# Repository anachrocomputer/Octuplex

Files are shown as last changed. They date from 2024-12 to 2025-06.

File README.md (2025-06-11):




# Octuplex #

A 6502/6809 microcomputer in the shape of an octagon.

## Microprocessor ##

A choice of two classic 8-bit CPUs, the 6502 or the 6809.
The two chips have similar pinouts and are placed on the PCB overlapping.
Only one chip may be installed at a time.
Clock speed 2MHz in both cases,
with the 68B09 requiring a 4x clock input,
i.e. 8MHz.
The Hitachi 63B09 may also be fitted.

## Timer ##

The standard Motorola MC6840 timer chip.
Can generate interrupts and/or PWM signals.

## Parallel I/O ##

The standard 6522 parallel port chip.
Can generate interrupts.

Two handy little circuits for additional 8-bit I/O with minimal pin count: 74LS259 and 74LS251.
The 74LS259 is an unusual chip, an addressable latch.
It takes three address input pins and a single data input pin,
and has eight output pins.
The 74LS251 is an eight-input multiplexer with tri-state output.
The selector inputs are connected to three address pins,
while the output is connected to data bit D7.
The 6502's BIT instruction can read D7 directly into the sign flag,
which can be followed by BMI or BPL.

## Analog I/O ##

The classic Ferranti ZN428 8-bit DAC chip.

The classic Ferranti ZN448 b-bit ADC chip.
Although I'm not sure about this one due to its need for a negative supply rail.

## I2C Bus ##

Classic Philips PCF8584 I2C bus controller.
Can generate interrupts.

## Async Serial I/O ##

Rockwell R65C52 dual ACIA.
Can generate interrupts.

Motorola MC6850 with optocoupler for MIDI.
Can generate interrupts.

## Display ##

TBD, most likely an LED starburst display of some kind.

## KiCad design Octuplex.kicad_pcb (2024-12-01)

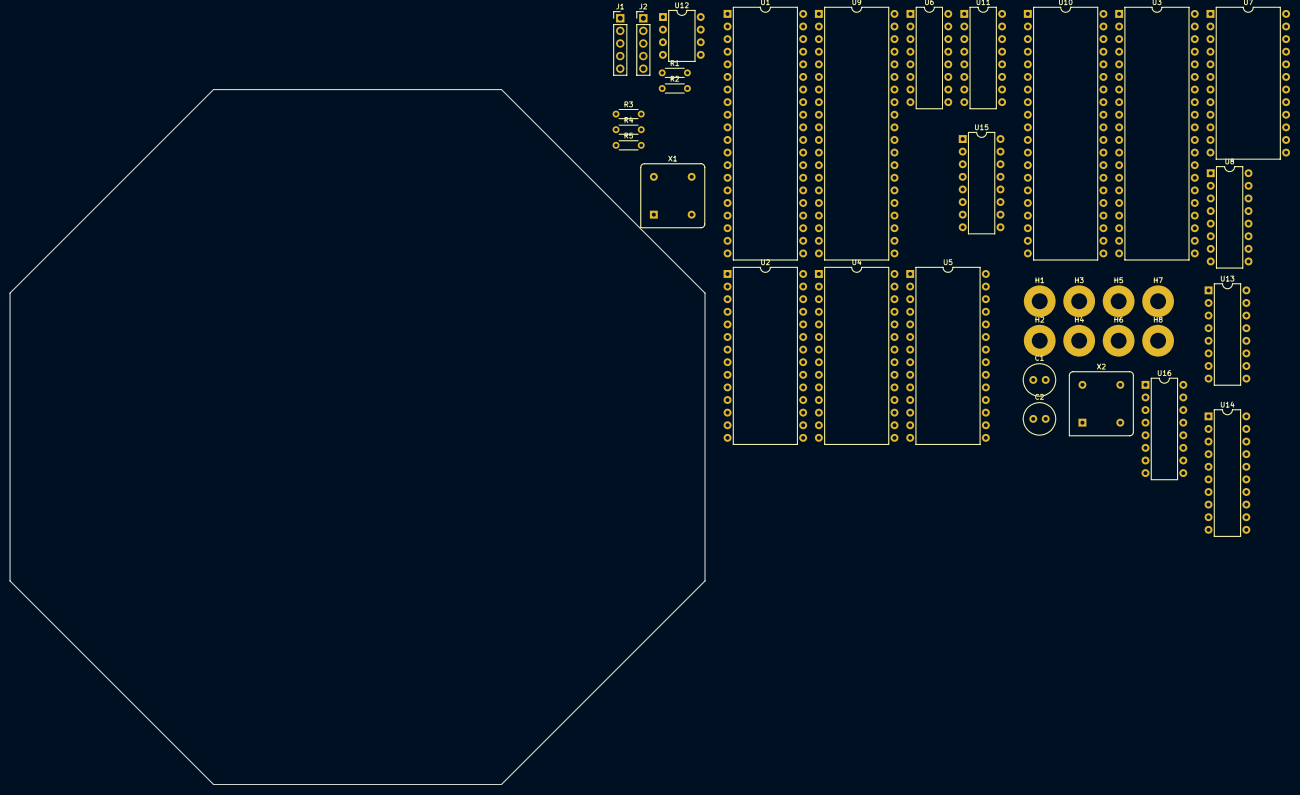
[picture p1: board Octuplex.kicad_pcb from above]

Board: 2 copper layers, 140.0 x 140.0 mm, 35 parts (0 on the bottom side), 44 nets, no tracks yet.

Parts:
C1, C2: 0.1uF; C_Radial_D6.3mm_H5.0mm_P2.50mm
H1, H2, H3, H4, H5, H6, H7, H8: MountingHole_Pad; MountingHole_3.2mm_M3_Pad
J1, J2: DIN-5_180degree; PinHeader_1x05_P2.54mm_Vertical
R1: 220; R_Axial_DIN0204_L3.6mm_D1.6mm_P5.08mm_Horizontal
R2: 280; R_Axial_DIN0204_L3.6mm_D1.6mm_P5.08mm_Horizontal
R3, R4, R5: 10k; R_Axial_DIN0204_L3.6mm_D1.6mm_P5.08mm_Horizontal
U1: MC68B09; DIP-40_W15.24mm
U2: MC68B40; DIP-28_W15.24mm
U3: R65C52; DIP-40_W15.24mm
U4: 27128; DIP-28_W15.24mm
U5: HM62256BLP; DIP-28_W15.24mm
U6: 74LS139; DIP-16_W7.62mm
U7: MC68B50; DIP-24_W15.24mm
U8: 74LS259; DIP-16_W7.62mm
U9: M6502; DIP-40_W15.24mm
U10: R6522; DIP-40_W15.24mm
U11, U15: 74LS138; DIP-16_W7.62mm
U12: HCPL-2631; DIP-8_W7.62mm
U13: 74LS251; DIP-16_W7.62mm
U14: PCF8584; DIP-20_W7.62mm
U16: ZN428; DIP-16_W7.62mm
X1, X2: CXO_DIP8; Oscillator_DIP-8

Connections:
/E: U1.34 (E), U2.17 (E), U6.3 (A1), U7.14 (E), U9.39 (E), U10.25 (E), U11.6 (E3)
/Microprocessor/~IOSEL: U6.10 (O2), U11.4 (E1), U15.4 (E1)
/Microprocessor/~ROMCS: U4.20 (~CE), U6.9 (O3)
/Microprocessor/~TIMERCS: U2.15 (~CS0), U15.15 (O0)
/R/~W: U1.32 (R/~W), U2.13 (R/~W), U3.38 (R/~W), U6.2 (A0), U7.13 (R/~W), U9.34 (R/~W), U10.22 (R/~W), U11.1 (A0)
/a0: U1.8 (A0), U2.10 (RS0), U3.35 (RS0), U4.10 (A0), U5.10 (A0), U7.11 (RS), U8.1 (A0), U9.9 (A0), U10.38 (RS0), U13.11 (S0), U14.6 (A0)
/a1: U1.9 (A1), U2.11 (RS1), U3.36 (RS1), U4.9 (A1), U5.9 (A1), U8.2 (A1), U9.10 (A1), U10.37 (RS1), U13.10 (S1)
/a2: U1.10 (A2), U2.12 (RS2), U3.37 (RS2), U4.8 (A2), U5.8 (A2), U8.3 (A2), U9.11 (A2), U10.36 (RS2), U13.9 (S2)
/a3: U1.11 (A3), U4.7 (A3), U5.7 (A3), U9.12 (A3), U10.35 (RS3)
/a4: U1.12 (A4), U4.6 (A4), U5.6 (A4), U9.13 (A4)
/a5: U1.13 (A5), U4.5 (A5), U5.5 (A5), U9.14 (A5)
/a6: U1.14 (A6), U4.4 (A6), U5.4 (A6), U9.15 (A6)
/a7: U1.15 (A7), U4.3 (A7), U5.3 (A7), U9.16 (A7)
/a8: U1.16 (A8), U4.25 (A8), U5.25 (A8), U9.17 (A8)
/a9: U1.17 (A9), U4.24 (A9), U5.24 (A9), U9.18 (A9)
/a10: U1.18 (A10), U4.21 (A10), U5.21 (A10), U9.19 (A10), U15.1 (A0)
/a11: U1.19 (A11), U4.23 (A11), U5.23 (A11), U9.20 (A11), U11.2 (A1), U15.2 (A1)
/a12: U1.20 (A12), U4.2 (A12), U5.2 (A12), U9.22 (A12), U11.3 (A2), U15.3 (A2)
/a13: U1.21 (A13), U4.26 (A13), U5.26 (A13), U9.23 (A13), U11.5 (E2), U15.6 (E3)
/a14: U1.22 (A14), U5.1 (A14), U6.14 (A0), U9.24 (A14)
/a15: U1.23 (A15), U5.20 (~CS), U6.13 (A1), U9.25 (A15)
/d0: U1.31 (D0), U2.25 (D0), U3.24 (D0), U4.11 (D0), U5.11 (Q0), U7.22 (D0), U9.33 (D0), U10.33 (D0), U14.7 (D0), U16.2 (D0)
/d1: U1.30 (D1), U2.24 (D1), U3.23 (D1), U4.12 (D1), U5.12 (Q1), U7.21 (D1), U9.32 (D1), U10.32 (D1), U14.8 (D1), U16.1 (D1)
/d2: U1.29 (D2), U2.23 (D2), U3.22 (D2), U4.13 (D2), U5.13 (Q2), U7.20 (D2), U9.31 (D2), U10.31 (D2), U14.9 (D2), U16.16 (D2)
/d3: U1.28 (D3), U2.22 (D3), U3.21 (D3), U4.15 (D3), U5.15 (Q3), U7.19 (D3), U9.30 (D3), U10.30 (D3), U14.11 (D3), U16.15 (D3)
/d4: U1.27 (D4), U2.21 (D4), U3.19 (D4), U4.16 (D4), U5.16 (Q4), U7.18 (D4), U9.29 (D4), U10.29 (D4), U14.12 (D4), U16.14 (D4)
/d5: U1.26 (D5), U2.20 (D5), U3.18 (D5), U4.17 (D5), U5.17 (Q5), U7.17 (D5), U9.28 (D5), U10.28 (D5), U14.13 (D5), U16.13 (D5)
/d6: U1.25 (D6), U2.19 (D6), U3.17 (D6), U4.18 (D6), U5.18 (Q6), U7.16 (D6), U9.27 (D6), U10.27 (D6), U14.14 (D6), U16.12 (D6)
/d7: U1.24 (D7), U2.18 (D7), U3.16 (D7), U4.19 (D7), U5.19 (Q7), U7.15 (D7), U9.26 (D7), U10.26 (D7), U13.5 (Y), U14.15 (D7), U16.11 (D7)
/~IRQ: U1.3 (~IRQ), U2.9 (~IRQ), U3.11 (~IRQ2), U3.29 (~IRQ1), U7.7 (~IRQ), U9.4 (~IRQ), U10.21 (~IRQ), U14.5 (~INT)
/~NMI: U1.2 (~NMI), U9.6 (~NMI)
/~RD: U4.22 (~OE), U5.22 (~OE), U6.7 (O3), U14.16 (~RD)
/~RESET: R3.2, U1.37 (~RESET), U2.8 (~RESET), U3.1 (~RESET), U8.15 (Clr), U9.40 (~RESET), U10.34 (~RESET), U14.19 (~RST)
/~WR: U5.27 (~WE), U6.6 (O2), U14.18 (~WR)
GND: C1.2, C2.2, H1.1, H2.1, H3.1, H4.1, H5.1, H6.1, H7.1, H8.1, J1.2, U1.1 (VSS), U2.1 (VSS), U3.20 (VSS), U4.14 (GND), U5.14 (GND), U6.1 (E), U6.8 (GND), U6.15 (E), U7.1 (VSS), U8.8 (GND), U9.1 (VSS), U9.21 (VSS), U10.1 (VSS), U11.8 (GND), U12.5 (GND), U13.8 (GND), U14.10 (VSS), U15.5 (E2), U15.8 (GND), U16.8 (AGND), U16.9 (DGND), X1.4 (GND), X2.4 (GND)
unnamed: J1.4, R1.2
unnamed: U1.38 (EXTAL), X1.5 (OUT)
unnamed: R4.2, U1.36 (MRDY)
unnamed: R5.2, U1.40 (~HALT)
unnamed: R1.1, U12.1 (A1)
unnamed: J1.5, U12.2 (C1)
unnamed: R2.2, U7.2 (Rx_Data), U12.7 (VO1)
unnamed: U16.6 (VREFIN), U16.7 (VREFOUT)
VCC: C1.1, C2.1, R2.1, R3.1, R4.1, R5.1, U1.7 (VCC), U2.14 (VCC), U2.16 (CS1), U3.40 (VCC), U4.28 (VCC), U5.28 (VCC), U6.16 (VCC), U7.8 (CS0), U7.10 (CS1), U7.12 (VCC), U8.16 (VCC), U9.8 (VCC), U10.20 (VCC), U10.24 (CS1), U11.16 (VCC), U12.8 (VCC), U13.16 (VCC), U14.20 (VDD), U15.16 (VCC), U16.10 (VCC), X1.8 (Vcc), X2.8 (Vcc)

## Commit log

2024-10-16 Initial commit of schematic and symbols.
    Just 6809, ROM, RAM, ACIA, timer so far. Not fully connected up yet.
    [Octuplex.kicad_pcb, Octuplex.kicad_sch]
2024-10-17 WIP: new symbols, initial PCB.
    Add 6502 and 6522 symbols. Add mounting holes, board edge, and parts to PCB. Begin wiring up.
    [Octuplex.kicad_pcb, Octuplex.kicad_sch]
2024-11-24 Break up schematic into hierarchial sheets.
    Connect sheets with address and data buses. TODO: add control bus.
    [Octuplex.kicad_pcb, Octuplex.kicad_sch, gpio.kicad_sch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]
2024-11-24 Update schematic.
    Pull-up resistors for 6809 signals. 74LS251 mux for 8 input pins. MIDI optoisolator. Wire up 74LS139 for RD and WR. Still many unconnected pins. TODO: connect sheets with control bus.
    [Octuplex.kicad_pcb, gpio.kicad_sch, microprocesssor.kicad_sch]
2024-11-25 Add INTS bus, address decoder, and I2C chip.
    INTS bus carries RESET, NMI, FIRQ, and IRQ. Only RESET and IRQ used so far. Philips PCF8584 I2C interface chp added. Address decoder added based on 74LS139 and two 74LS138s. TODO: add CTRL bus with E, R/W, RD, and WR.
    [Octuplex.kicad_sch, gpio.kicad_sch, microprocesssor.kicad_sch]
2024-11-26 Add control bus.
    R/W, E, RD, WR signals from microprocessor to GPIO.
    [Octuplex.kicad_pcb, Octuplex.kicad_sch, gpio.kicad_sch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]
2024-11-29 Replace 6551 with R65C52 (dual ACIA).
    New symbol for R65C52 in library. Two async serial ports in one 40-pin package. But it has no 'E' input. Also remove two misconnected WR and RD pins.
    [Octuplex.kicad_pcb, gpio.kicad_sch, microprocesssor.kicad_sch]
2024-12-01 Add ZN428 8-bit DAC.
    Add symbol for ZN428 and place it on the GPIO page.
    [Octuplex.kicad_pcb, Octuplex.kicad_sch, gpio.kicad_sch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]
2024-12-01 Add description of chips to be used.
    Still not sure about the ZN448 ADC -- can we find a better one that doesn't need the negative rail and the extra input bit for READY?
